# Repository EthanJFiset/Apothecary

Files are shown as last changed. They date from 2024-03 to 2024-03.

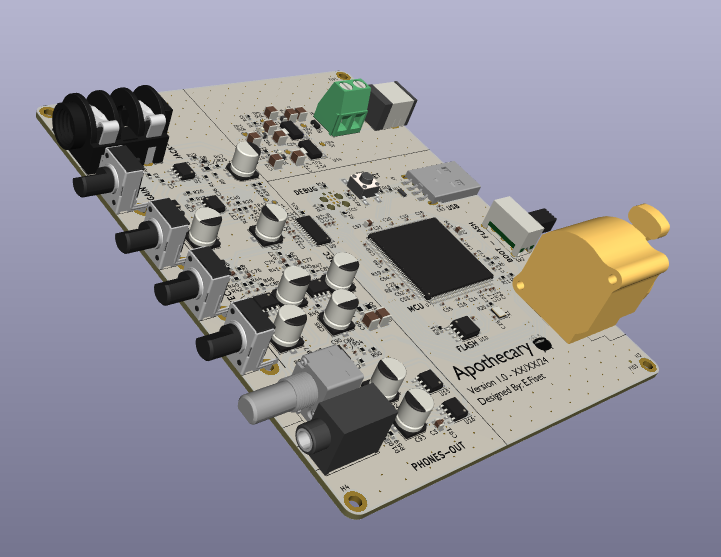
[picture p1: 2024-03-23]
Apothecary - DSP Development Board.png

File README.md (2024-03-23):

# Apothecary
Apothocary is an STM32H7-based USB audio interface and DSP board designed for prototyping real-time guitar effects. Features include a robust STM32H7 MCU complete with external SDRAM and QPSI flash memory, 24-bit 144-dB stereo codec, USB 2.0 connectivity and expansion ports for an external stomp box.

Apothecary - DSP Development Board

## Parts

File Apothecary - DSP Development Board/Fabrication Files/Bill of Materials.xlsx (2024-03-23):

Date: | 2024-03-13 13:44
Project: | Apothecary DSP Board v1.0
Tool: | Eeschema 7.0.9
Component Count: | 183
Ref | Qnty | Description | Footprint | Mfg. Part # | Mfg. | Type | Notes
C1, C2, C8, C12, C13, C14, C15, C16, C17, C18, C19, C20, C21, C22, C23, C25, C27, C28, C30, C31, C33, C36, C37, C38, C43, C44, C45, C46, C47, C48, C49, C50, C52, C54, C56, C58, C59, C60, C61, C88, C89, C90, C91, C94 | 44 | 100n CAP CER X7R 25V 10% | 0402 | C0402C104K3R | Kemet | SMD
C3, C4 | 2 | 10u CAP CER X5R 25V 10% | 0805 | C0805C106K3P7210 | Kemet | SMD
C5, C9, C10, C11, C24, C71, C72, C73, C95, C96 | 10 | 22u CAP CER X7R 24V 5% | 1210 | C1210C226K3PAC | Kemet | SMD
C26, C29, C32, C34, C53, C62, C63 | 7 | 1u CAP CER X7R 24V 5% | 0805 | C0805C105J3RECTU | Kemet | SMD
C35 | 1 | 47u CAP AL. ELC 25V 20% | SMD 6.3x6.3x8mm | EEV476M025A9GAA | Kemet | SMD
C39, C40, C78, C79, C80, C81 | 6 | 470p CAP CER C0G 25V 5% | 0402 | C0402C471J3G | Kemet | SMD
C42, C51, C55, C57 | 4 | 2u2 CAP CER X5R 24V 5% | 0805 | C0805C225K3P | Kemet | SMD
C74, C75, C76, C77, C41 | 4 | 2700p CAP CER C0G 25V 5% | 0603 | C0603C272J3G | Kemet | SMD
C6, C7, C82, C83, C84, C85, C92, C93 | 6 | 100u CAP AL. ELC 25V 20% | SMD 6.3x6.3x8mm | EEV227M025S9MAA | Kemet | SMD
C86, C87 | 2 | 100p CAP CER C0G 25V 5% | 0402 | C0402C101J3G | Kemet | SMD
D1, D2 | 2 | Schottky Diode Vf = 0.51 1A SBR 40Vrm | SOD-123 | 1N5819HW | Diodes Inc. | SMD
D3, D4 | 2 | Red LED, Vf = 2V @ 20mA | 0603 | 150060RS75000 | Wurth Elektronik | SMD
D7, D8, D9, D10 | 4 | ESD Diode 30 Vw, 0.15pF, 15kV Vc | 0603 | 0603ESDA-5N | Bussman-Eaton | SMD
FB1, FB2, FB3 | 3 | Ferrite Bead 1000MHz 10Ohm 3000mA AEC-Q200 | 0805 | 742792011 (https://www.mouser.be/ProductDetail/Wurth-Elektronik/742792011?qs=2kOmHSv6VfQxrmdQ6EIv1w%3D%3D) | Wurth Elektronik | SMD
J1 | 1 | 5-Pin Female XLR Jack | NC5FAH | NC5FAH | Neutrik | THT
J2 | 1 | 6.3mm Mono Female Jack | NMJ4HCD2 | NMJ4HCD2 | Neutrik | THT
J3 | 1 | Female USB 2.0 Jack, Middle mount | SMD | 0480372200 | Molex | SMD
J4 | 1 | Female DC Barrel Jack, 8.0A | THT | PJ-063AH | CUI Devices | THT
J5 | 1 | 3-Pin Stereo 3.5mm Phones Jack, Ground Connection | THT | SJ1-3535NG | CUI Devices | THT
J6 | 1 | 01x02 THT Screw Terminal Block | Terminal Block 1x02 P5.00mm | 1729128 | Pheonix Contact | THT
Q1 | 1 | P-Channel Enhancement Mode MOSFET | SOT-23 | NTR4502P | Onsemi | SMD
R1, R2, R3, R10, R26, R27, R29 | 7 | 680R RES OHM 1/10W .5% | 0603 | ERA-3AEB681V | Panasonic | SMD
R4, R6, R19, R20 | 6 | 33R RES OHM 1/10W .5% | 0603 | ERA-3AEB330V | Panasonic | SMD
R5, R8, R23, R31 | 4 | 20k RES OHM 1/10W .5% | 0603 | ERA-3AEB203V | Panasonic | SMD
R7, R42, R43, R44, R45, R50, R51 | 7 | 910R RES OHM 1/10W .5% | 0603 | ERA-3AEB911V | Panasonic | SMD
R9, R11, R36, R37, R38, R39, R40, R41, R46, R47, R54, R55, R58, R59 | 14 | 6K2 RES 1/10W .5% | 0603 | ERA-3AEB622V | Panasonic | SMD
R12, R18, R21, R48, R49, R52, R53 | 7 | 20K RES 1/10W .5% | 0603 | ERA-3AEB203V | Panasonic | SMD
R13, R14, R15, R16, R22, R28, R30, R32, R33 | 7 | 91R RES 1/10W .5% | 0603 | ERA-3AEB910V | Panasonic | SMD
R17, R60, R61 | 3 | 1M RES 1/8W .5% | 0805 | ERA-6AEB105V | Panasonic | SMD
R24 | 1 | 13K RES 1/10W .5% | 0603 | ERA-3AEB133V | Panasonic | SMD
R25 | 1 | 12K RES 1/10W .5% | 0603 | ERA-3AEB123V | Panasonic | SMD
RV1 | 1 | 1K OHM POT 1/10W 20% AUDIO TAPER | THT | PTV09A-2015F-A102 | Bourns | THT
RV2, RV3, RV4 | 3 | 10K OHM POT 1/10W 20% LINEAR TAPER | THT | PTV09A-2015F-B103 | Bourns | THT
RV5 | 1 | 10K OHM POT .025W 20% AUDIO TAPER, DUAL-GANGED | THT | PTD902-2015F-A103 | Bourns | THT
SW1 | 1 | SPST Push-button | SMD | TS04-66-50-BK-100-SMT | CUI Devices | SMD
SW2 | 1 | SPDT Horizontal Mounted Switch | THT | EG1224 | E-Switch | THT
U1, U2, U4, U5, U6 | 5 | Dual Rail-Rail Operational Amplifier | SOIC-8-1EP 3.9x4.9mm P1.27mm EP2.41x3.81mm | TLV9362IDR | Texas Instruments | SMD
U3 | 1 | 1A Low Dropout regulator, positive, 5.0V fixed output, SOT-223 | SOT-223 | AMS1117-5.0 | AMS | SMD
U7 | 1 | ARM Cortex-M7 MCU, 2048KB flash, 864KB RAM, 400MHz, 1.7-3.6V, 140 GPIO, LQFP-176 | LQFP-176 24x24mm P0.5mm | STM32H743IIT6 | ST Microelectronics | SMD
U8 | 1 | 128 Mb SDRAM, 3.3V, Up To 200MHz TSOP-II | TSOP-II-54 22.2x10.16mm P0.8mm | IS42S16800F-xTL | ISSI | SMD
U9 | 1 | 24-Bit, 192 kHz Stereo Audio CODEC, TSSOP-28 | TSSOP-28 4.4x9.7mm P0.65mm | CS4272-CZZR | Cirrus Logic | SMD
U10 | 1 | 128Mb Serial Flash Memory, Standard/Dual/Quad SPI, SOIC-8 | SOIC-8 5.23x5.23mm P1.27mm | W25Q128JVS | Winbond | SMD
U11 | 1 | USB2.0 ESD Array and Common-Mode Choke | SMD | ECMF02-4CMX8 | ST Microelectronics | SMD
U14 | 1 | 1A Low Dropout regulator, positive, 3.3V fixed output, SOT-223 | SOT-223-3 | AMS1117-3.3 | AMS | SMD
U15, U16 | 2 | High-Voltage High-Current Operational Amplifier, bandwidth 3MHz, slew-rate 15V/us, SOIC-8 | SOIC-8 3.9x4.9mm P1.27mm | OPA551U | Texas Instruments | SMD
X1 | 1 | Low Power Consumption Clock Oscillator - 26MHz | 3225-4Pin 3.2x2.5mm | OT2EL4C4JI-111OLP-26M | LCSC | SMD

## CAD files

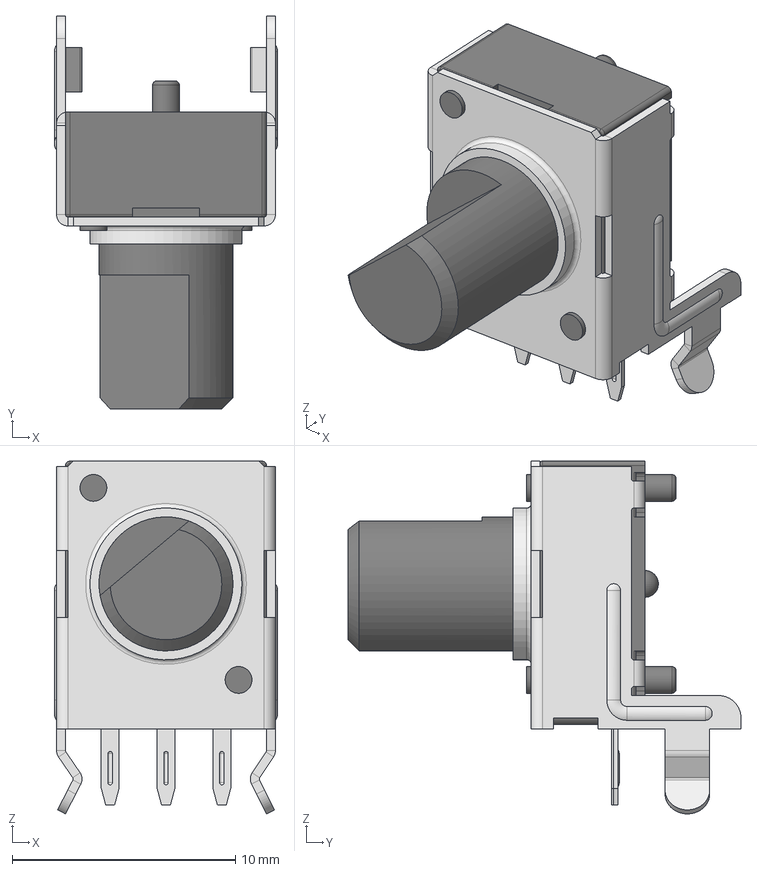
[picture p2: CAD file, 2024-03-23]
Apothecary - DSP Development Board/KiCAD Supplementary Files/3D Models/R-0901N-L-15F_H-6.5-black.step
10.0 x 17.6 x 15.8 mm

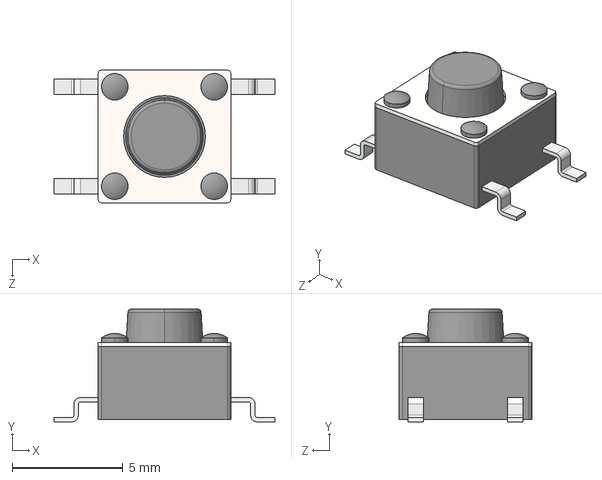
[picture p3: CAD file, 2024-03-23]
Apothecary - DSP Development Board/KiCAD Supplementary Files/3D Models/CUI_DEVICES_TS04-66-50-BK-260-SMT.step
10.0 x 5.10 x 6.00 mm

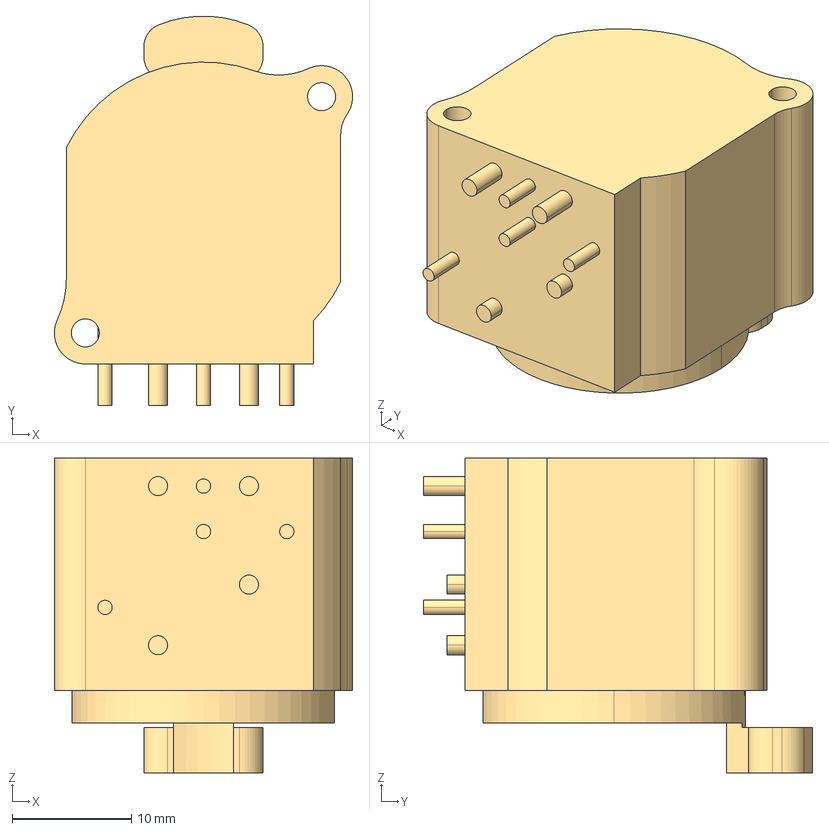
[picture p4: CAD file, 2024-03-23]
Apothecary - DSP Development Board/KiCAD Supplementary Files/3D Models/3-D NC5FAH.stp
25.0 x 32.6 x 26.4 mm

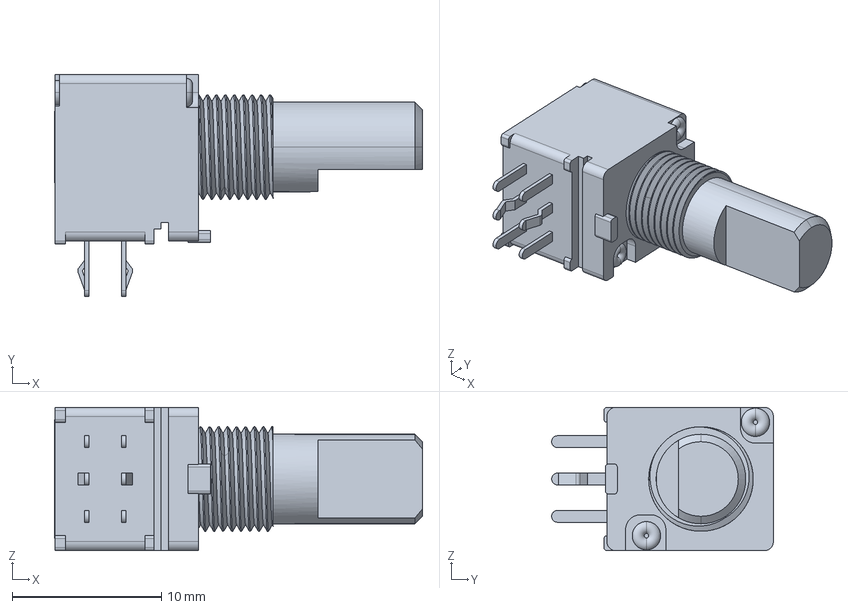
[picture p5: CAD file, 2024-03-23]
Apothecary - DSP Development Board/KiCAD Supplementary Files/3D Models/ptd902-xx15f-xxxx.stp
24.7 x 14.9 x 9.60 mm

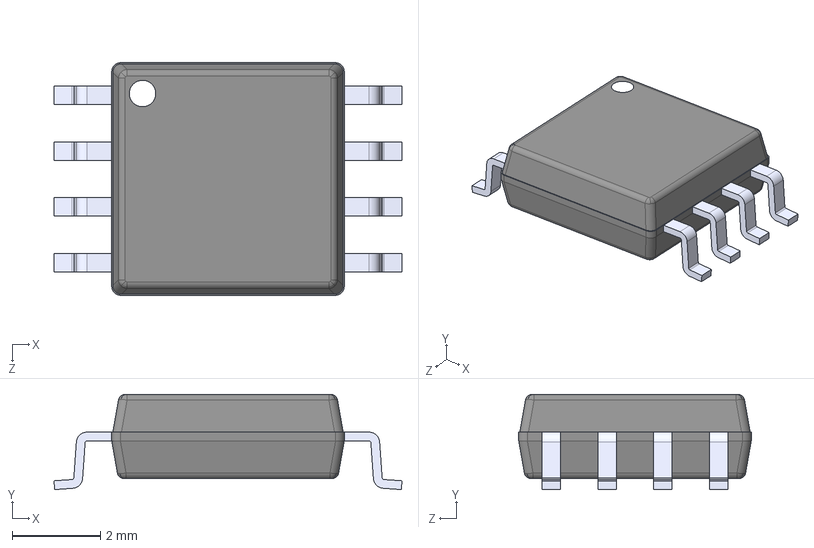
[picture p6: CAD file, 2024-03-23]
Apothecary - DSP Development Board/KiCAD Supplementary Files/3D Models/W25Q128JVSIM.STEP
7.90 x 2.16 x 5.28 mm

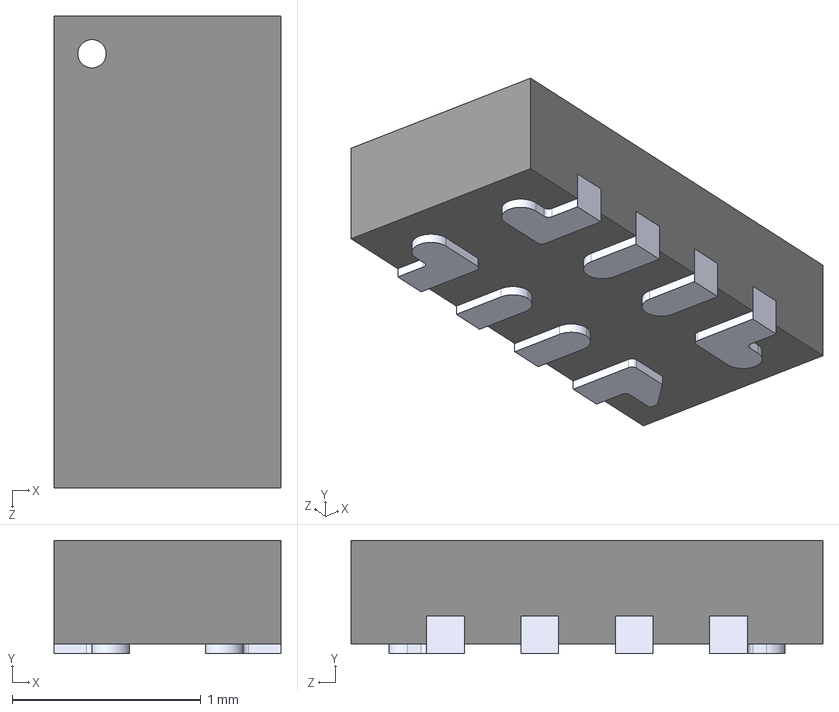
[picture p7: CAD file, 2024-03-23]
Apothecary - DSP Development Board/KiCAD Supplementary Files/3D Models/ECMF02-4CMX8--3DModel-STEP-510211.STEP
1.20 x 0.6 x 2.50 mm

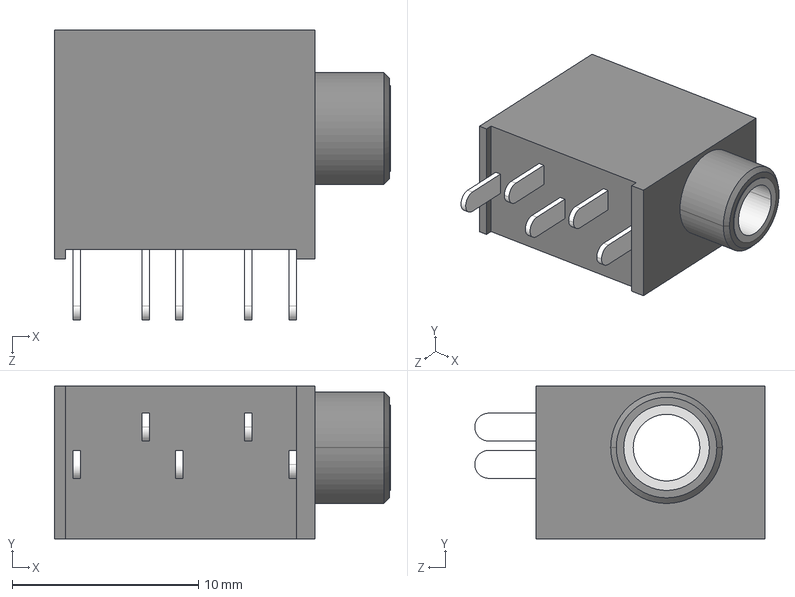
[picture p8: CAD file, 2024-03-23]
Apothecary - DSP Development Board/KiCAD Supplementary Files/3D Models/CUI_DEVICES_SJ1-3535NG.step
18.1 x 8.20 x 15.6 mm

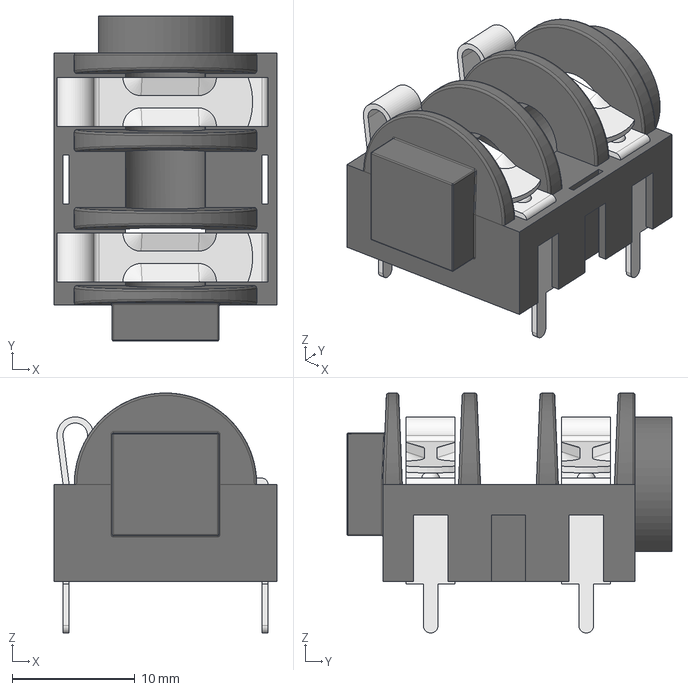
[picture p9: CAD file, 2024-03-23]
Apothecary - DSP Development Board/KiCAD Supplementary Files/3D Models/NMJ4HCD2.step
18.2 x 26.5 x 19.6 mm

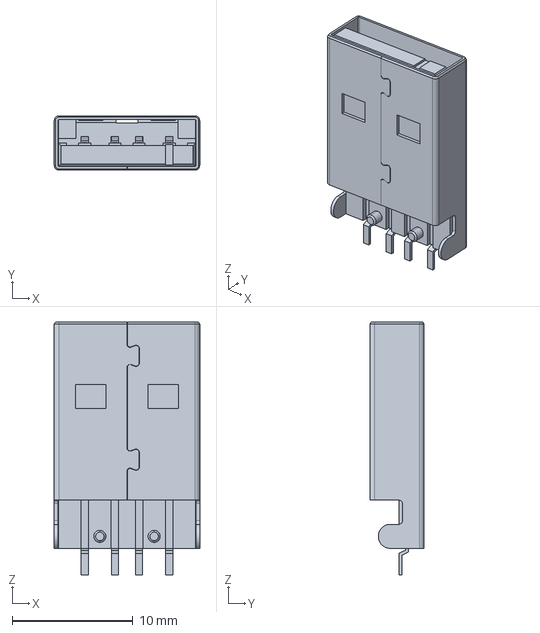
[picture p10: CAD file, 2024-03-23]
Apothecary - DSP Development Board/KiCAD Supplementary Files/3D Models/0480372200.step
12.1 x 4.50 x 21.0 mm

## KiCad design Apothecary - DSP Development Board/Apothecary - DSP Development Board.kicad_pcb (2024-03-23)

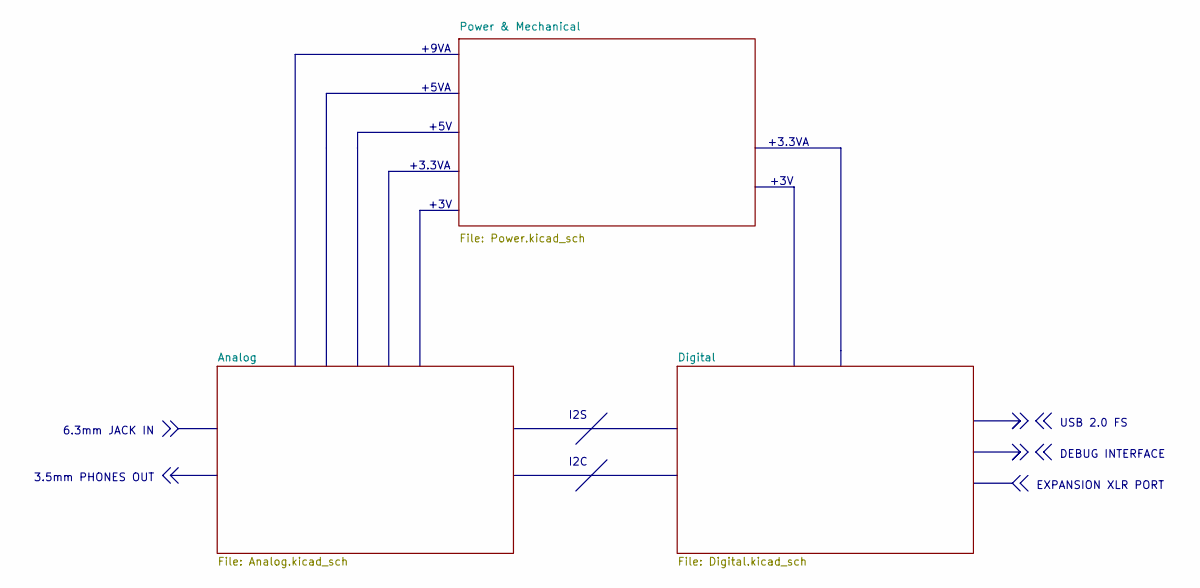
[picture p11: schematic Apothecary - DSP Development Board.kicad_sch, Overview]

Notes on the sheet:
+9VA
+3V
EXPANSION XLR PORT
6.3mm JACK IN
DEBUG INTERFACE
USB 2.0 FS
+5V
I2C
+3.3VA
3.5mm PHONES OUT
+5VA
I2S

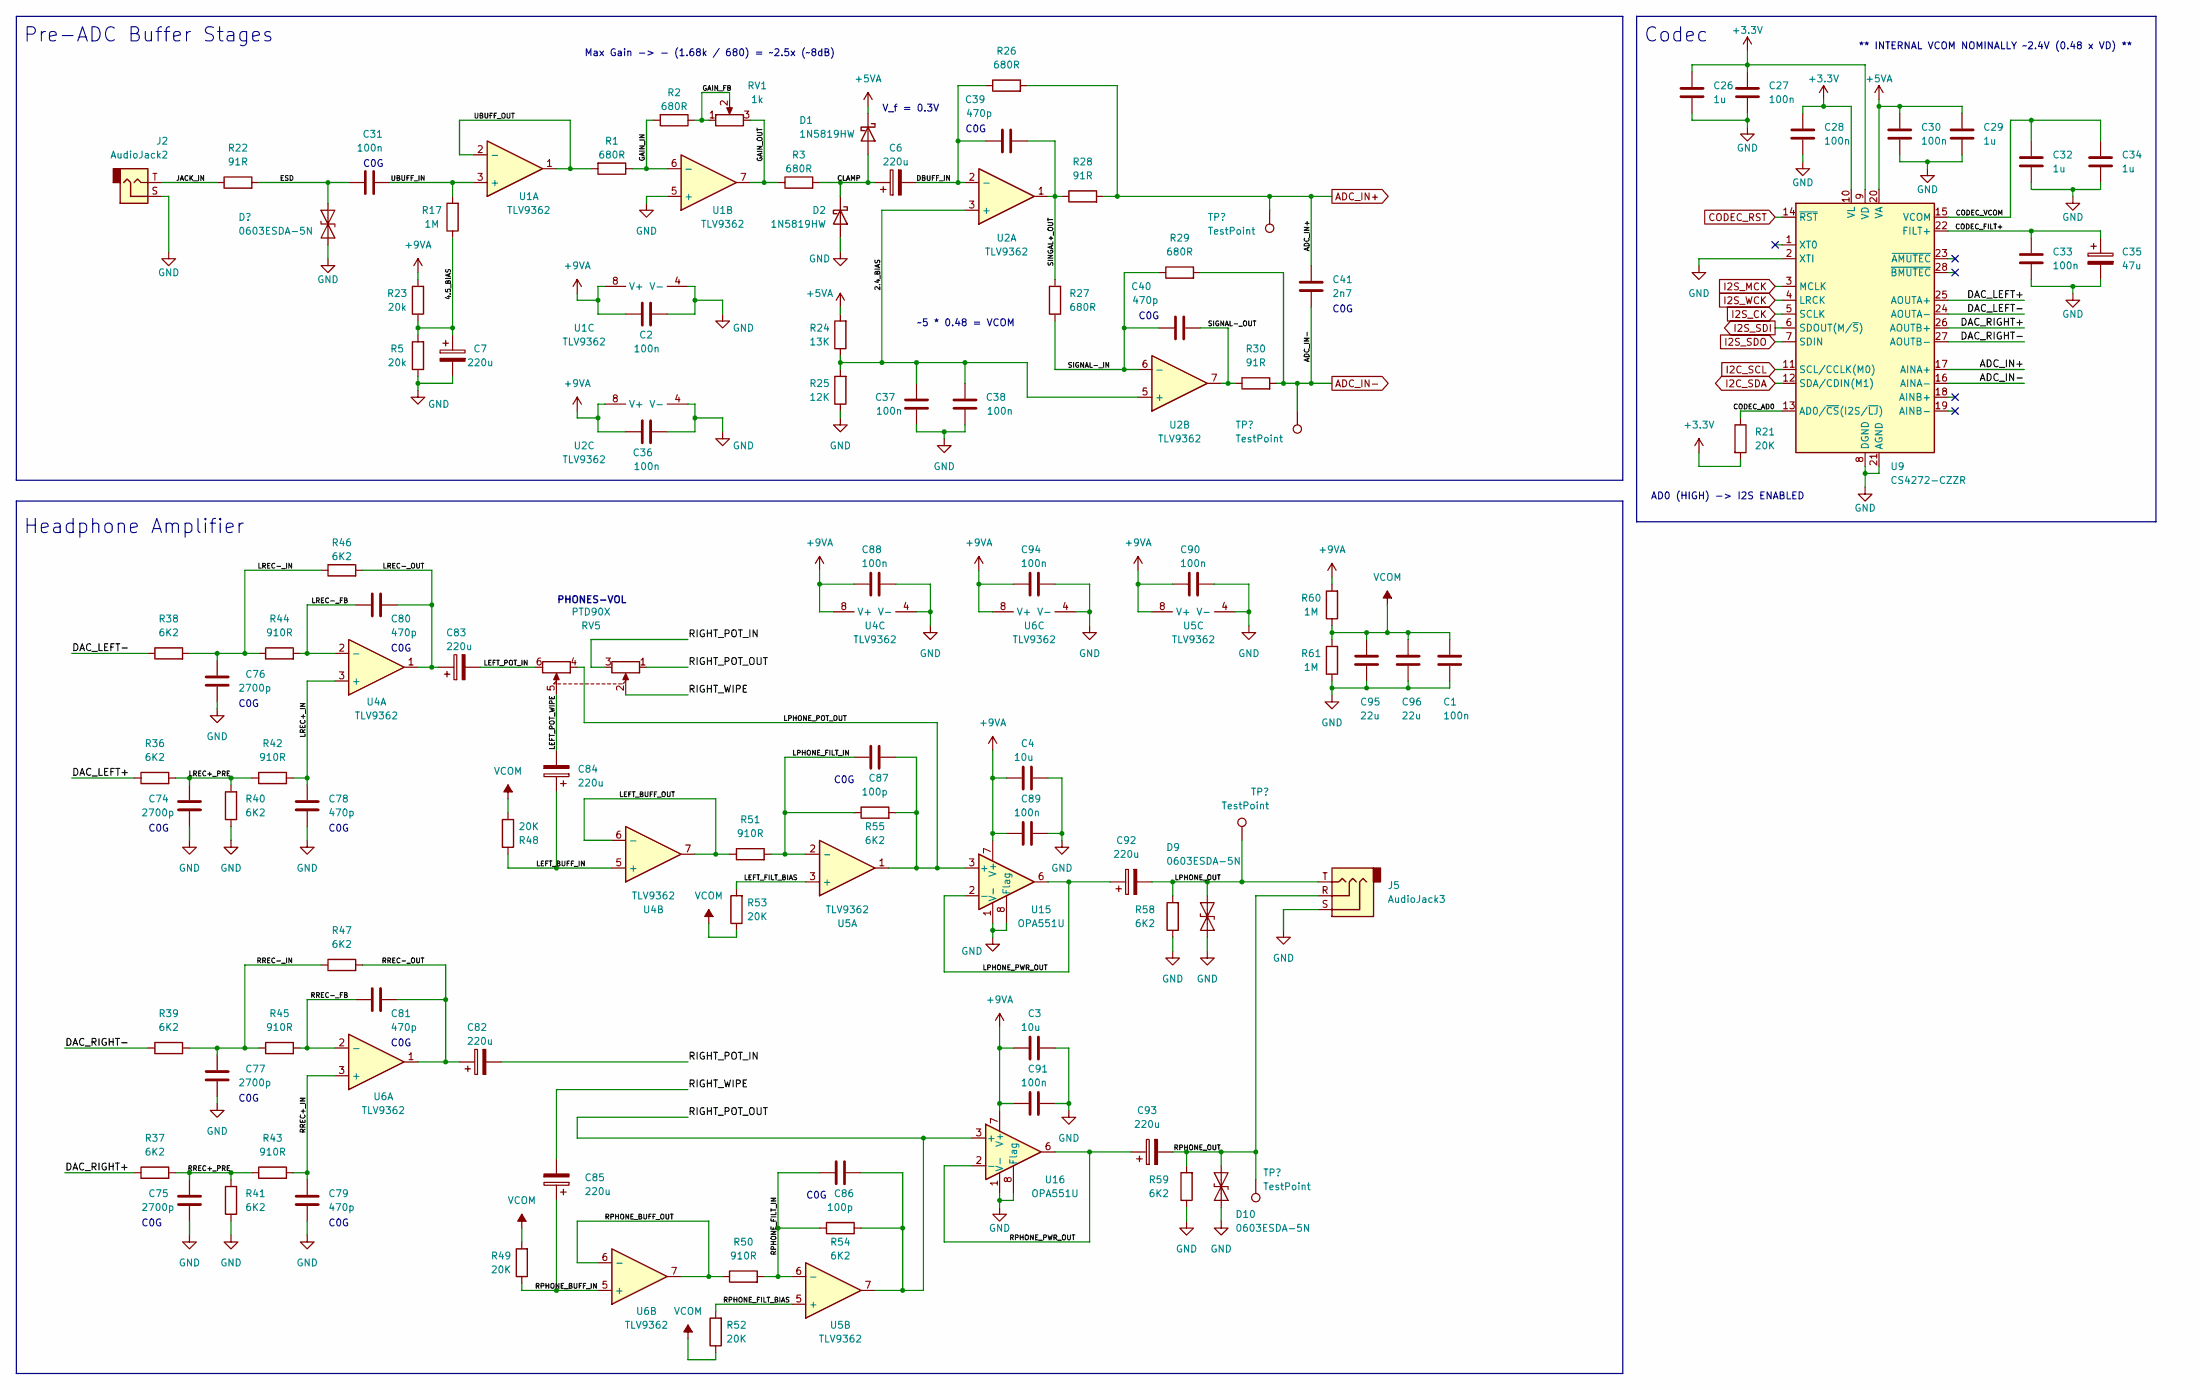
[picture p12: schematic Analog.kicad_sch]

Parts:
C1, C2, C27, C28, C30, C31, C33, C36, C37, C38, C88, C89, C90, C91, C94: 100n; C_0402_1005Metric
C3, C4: 10u; C_0805_2012Metric
C6, C7, C82, C83, C84, C85, C92, C93: 220u; CP_Elec_6.3x7.7
C26, C29, C32, C34: 1u; C_0402_1005Metric
C35: 47u; CP_Elec_6.3x7.7
C39, C40, C78, C79, C80, C81: 470p; C_0402_1005Metric
C41: 2n7; C_0603_1608Metric
C74, C75, C76, C77: 2700p; C_0603_1608Metric
C86, C87: 100p; C_0402_1005Metric
C95, C96: 22u; C_1210_3225Metric
D1, D2: 1N5819HW; D_SOD-123
D8, D9, D10: 0603ESDA-5N; D_0603_1608Metric
J2: AudioJack2; Jack_6.35mm_Neutrik_NMJ4HCD2_Horizontal
J5: AudioJack3; Jack_3.5mm_CUI_SJ1-3533NG_Horizontal
R1, R2, R3, R26, R27, R29: 680R; R_0603_1608Metric
R5, R23: 20k; R_0603_1608Metric
R17, R60, R61: 1M; R_0805_2012Metric
R21, R48, R49, R52, R53: 20K; R_0603_1608Metric
R22, R28, R30: 91R; R_0603_1608Metric
R24: 13K; R_0603_1608Metric
R25: 12K; R_0603_1608Metric
R36, R37, R38, R39, R40, R41, R46, R47, R54, R55, R58, R59: 6K2; R_0603_1608Metric
R42, R43, R44, R45, R50, R51: 910R; R_0603_1608Metric
RV1: 1k; Potentiometer_Bourns_PTV09A-2_Single_Horizontal
RV5: PTD90X; PTD-902
TP11, TP12, TP13, TP14: TestPoint; TestPoint_Pad_D1.0mm
U1, U2, U4, U5, U6: TLV9362; SOIC-8-1EP_3.9x4.9mm_P1.27mm_EP2.41x3.81mm
U9: CS4272-CZZR; TSSOP-28_4.4x9.7mm_P0.65mm
U15, U16: OPA551U; SOIC-8_3.9x4.9mm_P1.27mm

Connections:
+3.3V: C26.1, C27.1, C28.1, R21.2, U9.9 (VD), U9.10 (VL); also elsewhere on the board
+5VA: C29.1, C30.1, D1.1 (K), R24.2, U9.20 (VA); also elsewhere on the board
+9VA: C2.1, C3.2, C4.2, C36.1, C88.2, C89.2, C90.2, C91.2, C94.2, R23.2, R60.2, U1.8 (V+), U2.8 (V+), U4.8 (V+), U5.8 (V+), U6.8 (V+), U15.7 (V+), U16.7 (V+); also elsewhere on the board
/Analog/2.4_BIAS: C37.2, C38.2, R24.1, R25.2, U2.3 (+), U2.5 (+)
/Analog/4.5_BIAS: C7.1, R5.2, R17.1, R23.1
/Analog/CLAMP: C6.1, D1.2 (A), D2.1 (K), R3.2
/Analog/CODEC_AD0: R21.1, U9.13 (AD0/~CS(I2S/~LJ))
/Analog/CODEC_FILT+: C33.1, C35.1, U9.22 (FILT+)
/Analog/CODEC_VCOM: C32.1, C34.1, U9.15 (VCOM)
/Analog/DAC_LEFT+: R36.1, U9.25 (AOUTA+)
/Analog/DAC_LEFT-: R38.1, U9.24 (AOUTA-)
/Analog/DAC_RIGHT+: R37.1, U9.26 (AOUTB+)
/Analog/DAC_RIGHT-: R39.1, U9.27 (AOUTB-)
/Analog/DBUFF_IN: C6.2, C39.1, R26.1, U2.2 (-)
/Analog/ESD: C31.1, D8.2 (A2), R22.2
/Analog/GAIN_FB: R2.1, RV1.1, RV1.2
/Analog/GAIN_IN: R1.1, R2.2, U1.6 (-)
/Analog/GAIN_OUT: R3.1, RV1.3, U1.7
/Analog/JACK_IN: J2.T, R22.1
/Analog/LEFT_BUFF_IN: C84.1, R48.2, U4.5 (+)
/Analog/LEFT_BUFF_OUT: R51.1, U4.6 (-), U4.7
/Analog/LEFT_FILT_BIAS: R53.2, U5.3 (+)
/Analog/LEFT_POT_IN: C83.2, RV5.6
/Analog/LEFT_POT_WIPE: C84.2, RV5.5
/Analog/LPHONE_FILT_IN: C87.2, R51.2, R55.1, U5.2 (-)
/Analog/LPHONE_OUT: C92.2, D9.2 (A2), J5.T, R58.2, TP13.1
/Analog/LPHONE_POT_OUT: C87.1, R55.2, RV5.4, U5.1, U15.3 (+)
/Analog/LPHONE_PWR_OUT: C92.1, U15.2 (-), U15.6
/Analog/LREC+_IN: C78.1, R42.2, U4.3 (+)
/Analog/LREC+_PRE: C74.1, R36.2, R40.2, R42.1
/Analog/LREC-_FB: C80.2, R44.2, U4.2 (-)
/Analog/LREC-_IN: C76.1, R38.2, R44.1, R46.1
/Analog/LREC-_OUT: C80.1, C83.1, R46.2, U4.1
/Analog/RIGHT_POT_IN: C82.2, RV5.3
/Analog/RIGHT_POT_OUT: C86.1, R54.2, RV5.1, U5.7, U16.3 (+)
/Analog/RIGHT_WIPE: C85.2, RV5.2
/Analog/RPHONE_BUFF_IN: C85.1, R49.1, U6.5 (+)
/Analog/RPHONE_BUFF_OUT: R50.1, U6.6 (-), U6.7
/Analog/RPHONE_FILT_BIAS: R52.2, U5.5 (+)
/Analog/RPHONE_FILT_IN: C86.2, R50.2, R54.1, U5.6 (-)
/Analog/RPHONE_OUT: C93.2, D10.2 (A2), J5.R, R59.2, TP14.1
/Analog/RPHONE_PWR_OUT: C93.1, U16.2 (-), U16.6
/Analog/RREC+_IN: C79.1, R43.2, U6.3 (+)
/Analog/RREC+_PRE: C75.1, R37.2, R41.2, R43.1
/Analog/RREC-_FB: C81.2, R45.2, U6.2 (-)
/Analog/RREC-_IN: C77.1, R39.2, R45.1, R47.1
/Analog/RREC-_OUT: C81.1, C82.1, R47.2, U6.1
/Analog/SIGNAL-_IN: C40.1, R27.1, R29.1, U2.6 (-)
/Analog/SIGNAL-_OUT: C40.2, R30.1, U2.7
/Analog/SINGAL+_OUT: C39.2, R27.2, R28.1, U2.1
/Analog/UBUFF_IN: C31.2, R17.2, U1.3 (+)
/Analog/UBUFF_OUT: R1.2, U1.1, U1.2 (-)
ADC_IN+: C41.1, R26.2, R28.2, TP12.1, U9.17 (AINA+)
ADC_IN-: C41.2, R29.2, R30.2, TP11.1, U9.16 (AINA-)
CODEC_RST: U9.14 (~RST); also elsewhere on the board
GND: C1.2, C2.2, C3.1, C4.1, C7.2, C26.2, C27.2, C28.2, C29.2, C30.2, C32.2, C33.2, C34.2, C35.2, C36.2, C37.1, C38.1, C74.2, C75.2, C76.2, C77.2, C78.2, C79.2, C88.1, C89.1, C90.1, C91.1, C94.1, C95.2, C96.2, D2.2 (A), D8.1 (A1), D9.1 (A1), D10.1 (A1), J2.S, J5.S, R5.1, R25.1, R40.1, R41.1, R58.1, R59.1, R61.1, U1.4 (V-), U1.5 (+), U2.4 (V-), U4.4 (V-), U5.4 (V-), U6.4 (V-), U9.2 (XTI), U9.8 (DGND), U9.21 (AGND), U15.1 (V-), U15.4 (V-), U15.5 (V-), U15.8 (Flag), U16.1 (V-), U16.4 (V-), U16.5 (V-), U16.8 (Flag); also elsewhere on the board
I2C_SCL: U9.11 (SCL/CCLK(M0)); also elsewhere on the board
I2C_SDA: U9.12 (SDA/CDIN(M1)); also elsewhere on the board
I2S_CK: U9.5 (SCLK); also elsewhere on the board
I2S_MCK: U9.3 (MCLK); also elsewhere on the board
I2S_SDI: U9.6 (SDOUT(M/~S)); also elsewhere on the board
I2S_SDO: U9.7 (SDIN); also elsewhere on the board
I2S_WCK: U9.4 (LRCK); also elsewhere on the board
VCOM: C1.1, C95.1, C96.1, R48.1, R49.2, R52.1, R53.1, R60.1, R61.2

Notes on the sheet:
C0G
Pre-ADC Buffer Stages
** INTERNAL VCOM NOMINALLY ~2.4V (0.48 x VD) **
Headphone Amplifier
V_f = 0.3V
PHONES-VOL
Codec
~5 * 0.48 = VCOM
AD0 (HIGH) -> I2S ENABLED
Max Gain -> - (1.68k / 680) = ~2.5x (~8dB)

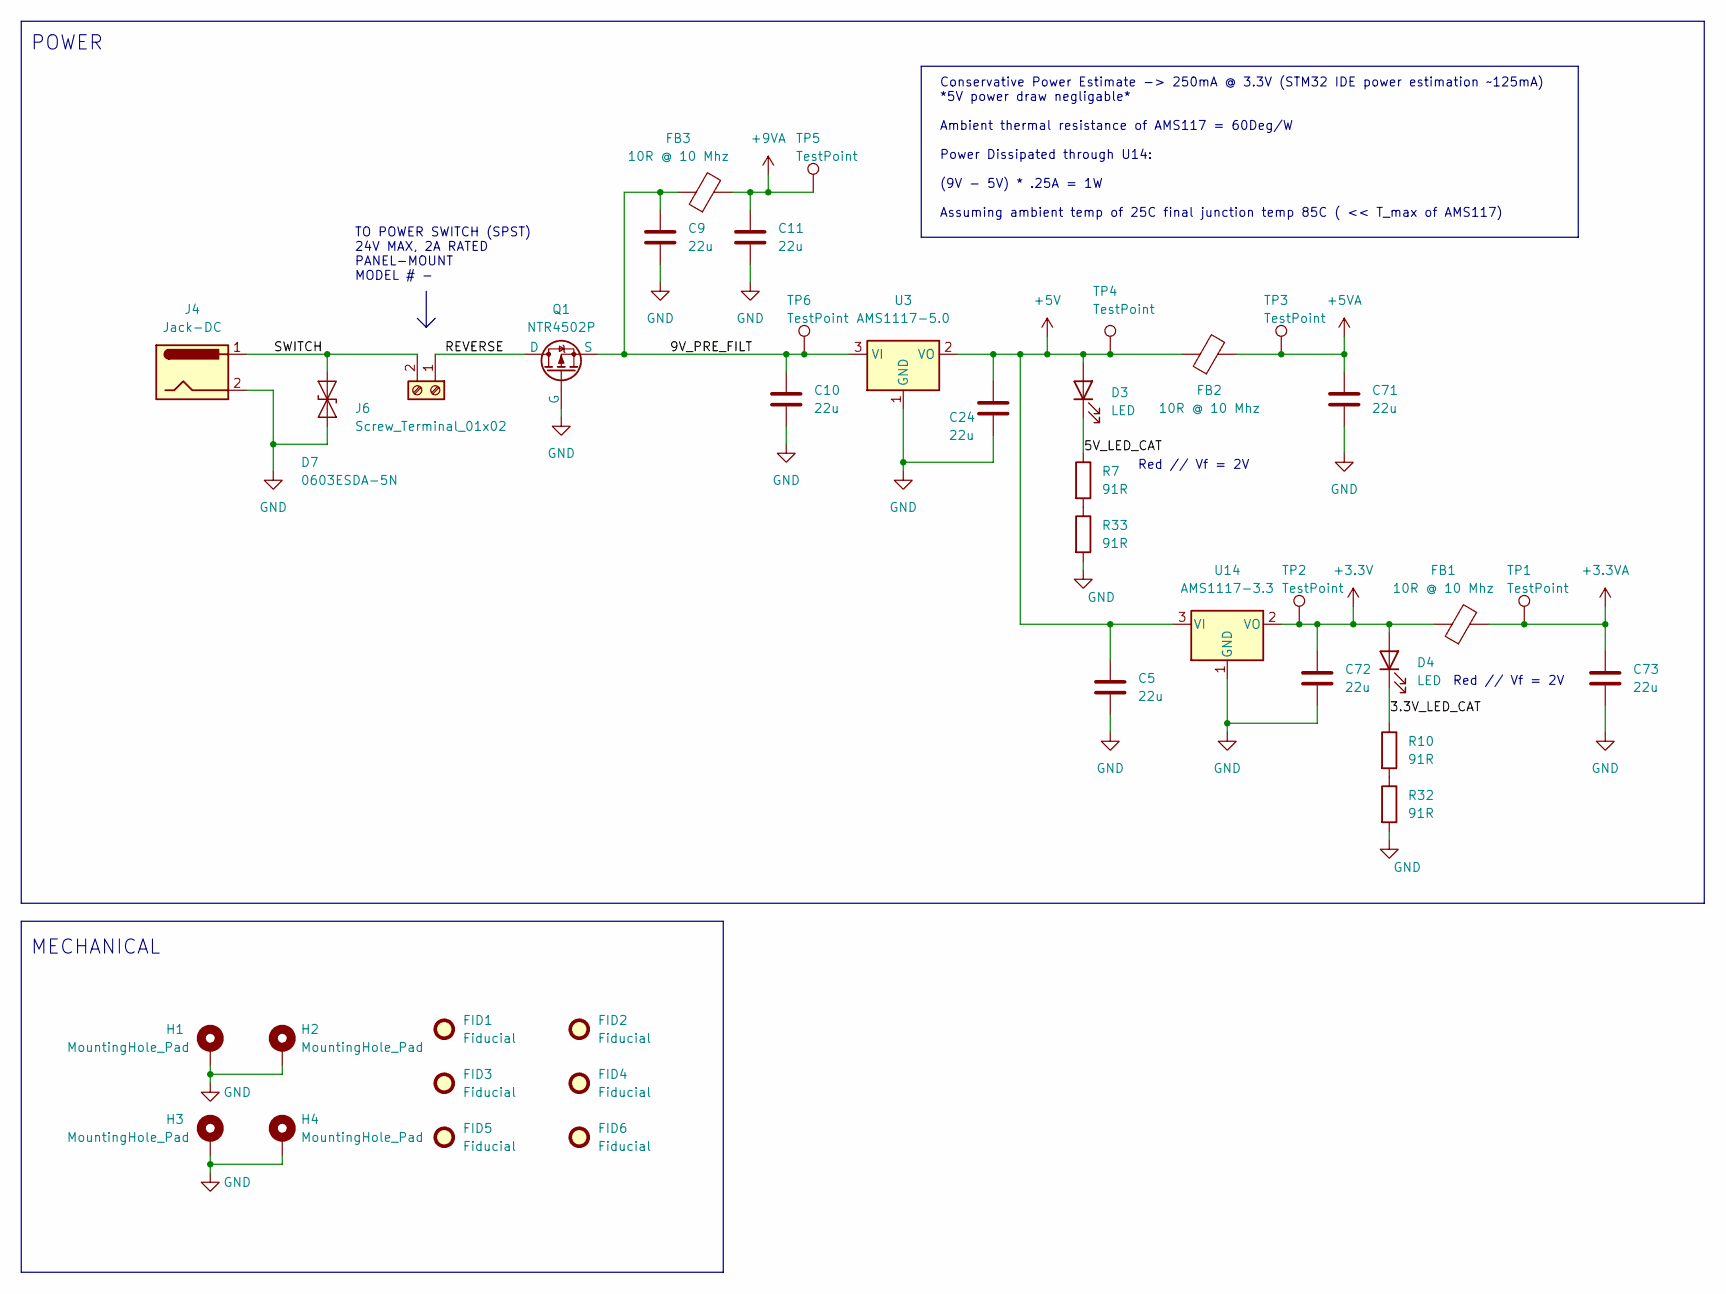
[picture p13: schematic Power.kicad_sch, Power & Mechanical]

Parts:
C5, C9, C10, C11, C24, C71, C72, C73: 22u; C_1210_3225Metric
D3, D4: LED; LED_0603_1608Metric
D7: 0603ESDA-5N; D_0603_1608Metric
FB1, FB2, FB3: 10R @ 10 Mhz; L_0805_2012Metric
FID1, FID2, FID3, FID4, FID5, FID6: Fiducial; Fiducial_0.5mm_Mask1mm
H1, H2, H3, H4: MountingHole_Pad; MountingHole_2.7mm_M2.5_DIN965_Pad
J4: Jack-DC; BarrelJack_CUI_PJ-063AH_Horizontal
J6: Screw_Terminal_01x02; TerminalBlock_Phoenix_MKDS-1,5-2_1x02_P5.00mm_Horizontal
Q1: NTR4502P; SOT-23
R7, R10, R32, R33: 91R; R_0603_1608Metric
TP1, TP2, TP3, TP4, TP5, TP6: TestPoint; TestPoint_Pad_D1.5mm
U3: AMS1117-5.0; SOT-223-3_TabPin2
U14: AMS1117-3.3; SOT-223-3_TabPin2

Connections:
+3.3V: C72.2, D4.2 (A), FB1.1, TP2.1, U14.2 (VO); also elsewhere on the board
+3.3VA: C73.2, FB1.2, TP1.1; also elsewhere on the board
+5V: C5.2, C24.2, D3.2 (A), FB2.1, TP4.1, U3.2 (VO), U14.3 (VI)
+5VA: C71.2, FB2.2, TP3.1; also elsewhere on the board
+9VA: C11.2, FB3.2, TP5.1; also elsewhere on the board
/Power & Mechanical/3.3V_LED_CAT: D4.1 (K), R10.1
/Power & Mechanical/5V_LED_CAT: D3.1 (K), R7.1
/Power & Mechanical/9V_PRE_FILT: C9.2, C10.2, FB3.1, Q1.3 (S), TP6.1, U3.3 (VI)
/Power & Mechanical/REVERSE: J6.1, Q1.1 (D)
/Power & Mechanical/SWITCH: D7.2 (A2), J4.1, J6.2
GND: C5.1, C9.1, C10.1, C11.1, C24.1, C71.1, C72.1, C73.1, D7.1 (A1), H1.1, H2.1, H3.1, H4.1, J4.2, Q1.2 (G), R32.2, R33.2, U3.1 (GND), U14.1 (GND); also elsewhere on the board
unnamed: R10.2, R32.1
unnamed: R7.2, R33.1

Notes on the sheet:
Conservative Power Estimate -> 250mA @ 3.3V (STM32 IDE power estimation ~125mA) *5V power draw negligable* Ambient thermal resistance of AMS117 = 60Deg/W Power Dissipated through U14: (9V - 5V) * .25A = 1W Assuming ambient temp of 25C final junction temp 85C ( << T_max of AMS117)
TO POWER SWITCH (SPST) 24V MAX, 2A RATED PANEL-MOUNT MODEL # -
MECHANICAL
POWER
Red // Vf = 2V

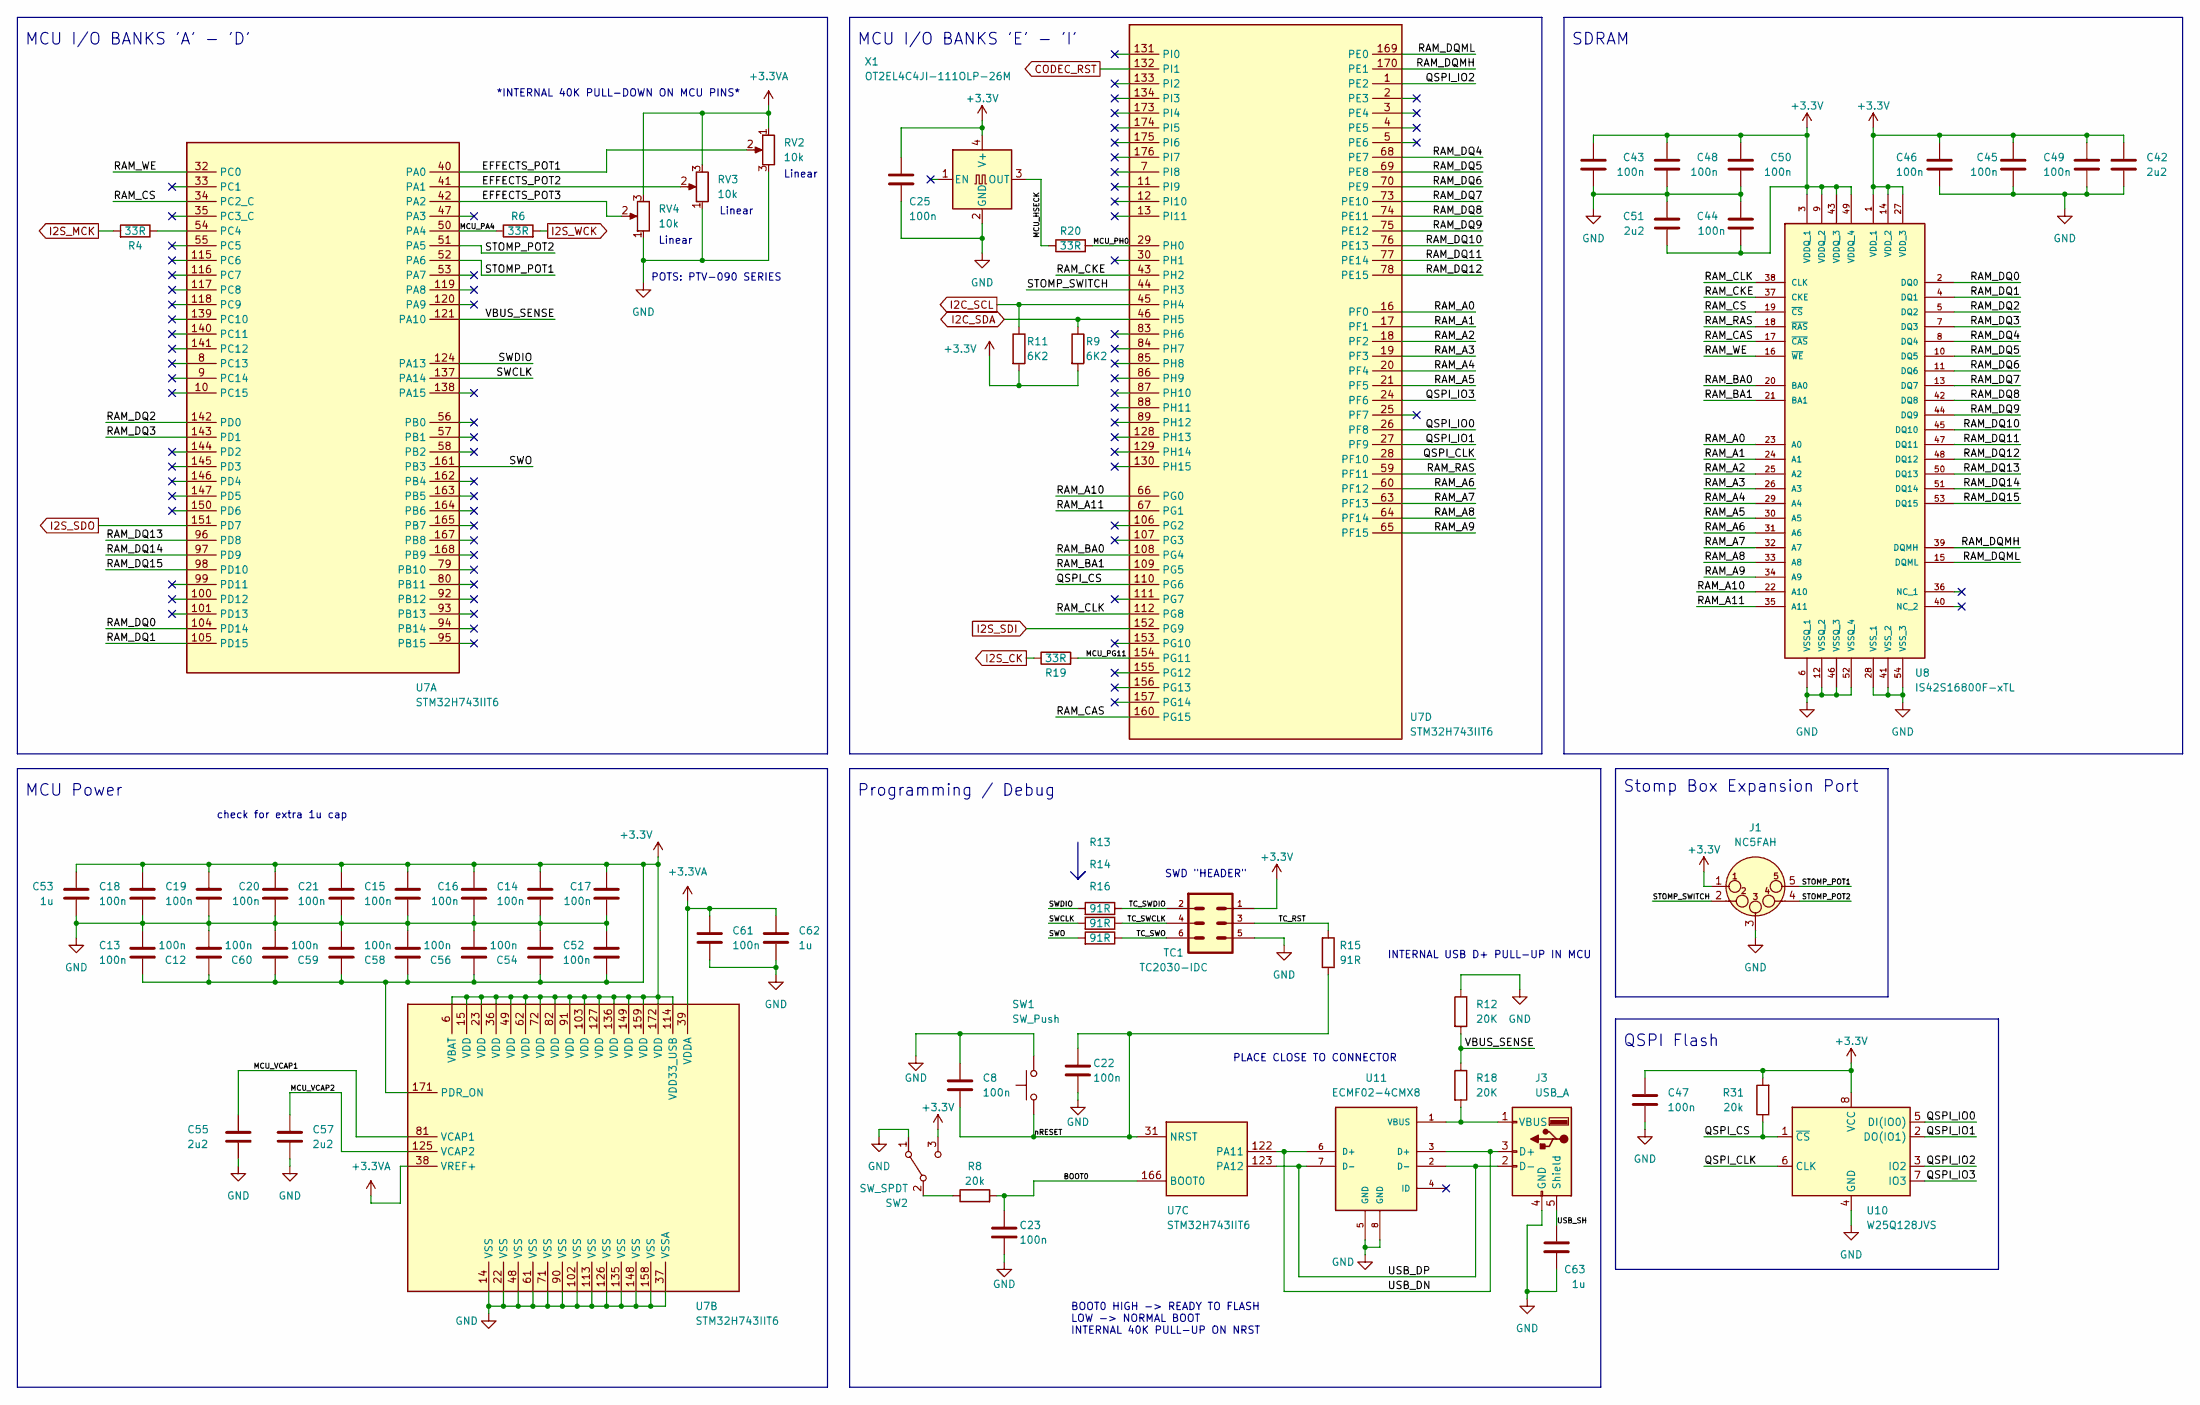
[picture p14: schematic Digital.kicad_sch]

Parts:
C8, C12, C13, C14, C15, C16, C17, C18, C19, C20, C21, C22, C23, C25, C43, C44, C45, C46, C47, C48, C49, C50, C52, C54, C56, C58, C59, C60, C61: 100n; C_0402_1005Metric
C42, C51, C55, C57: 2u2; C_0805_2012Metric
C53, C62, C63: 1u; C_0402_1005Metric
J1: NC5FAH; Jack_XLR_Neutrik_NC5FAH_Horizontal
J3: USB_A; MOLEX_0480372200
R4, R6, R19, R20: 33R; R_0603_1608Metric
R8, R31: 20k; R_0603_1608Metric
R9, R11: 6K2; R_0603_1608Metric
R12, R18: 20K; R_0603_1608Metric
R13, R14, R15, R16: 91R; R_0603_1608Metric
RV2, RV3, RV4: 10k; Potentiometer_Bourns_PTV09A-2_Single_Horizontal
SW1: SW_Push; Pushbutton_CUI_TS04
SW2: SW_SPDT; SW_E-Switch_EG1224_SPDT_Angled
TC1: TC2030-IDC; Tag-Connect_TC2030-IDC-FP_2x03_P1.27mm_Vertical
U7: STM32H743IIT6; LQFP-176_24x24mm_P0.5mm
U8: IS42S16800F-xTL; TSOP-II-54_22.2x10.16mm_P0.8mm; MOUSER_PART_NUMBER 870-IS42S16800F-7TL
U10: W25Q128JVS; SOIC-8_5.23x5.23mm_P1.27mm
U11: ECMF02-4CMX8; FIL_ECMF02-4CMX8; PARTREV 3
X1: OT2EL4C4JI-111OLP-26M; Crystal_SMD_3225-4Pin_3.2x2.5mm

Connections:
+3.3V: C12.1, C13.1, C14.2, C15.2, C16.2, C17.2, C18.2, C19.2, C20.2, C21.2, C25.1, C42.2, C43.2, C44.1, C45.2, C46.2, C47.1, C48.2, C49.2, C50.2, C51.1, C52.1, C53.2, C54.1, C56.1, C58.1, C59.1, C60.1, J1.1, R9.2, R11.2, R31.2, SW2.3 (C), TC1.1, U7.6 (VBAT), U7.15 (VDD), U7.23 (VDD), U7.36 (VDD), U7.49 (VDD), U7.62 (VDD), U7.72 (VDD), U7.82 (VDD), U7.91 (VDD), U7.103 (VDD), U7.114 (VDD33_USB), U7.127 (VDD), U7.136 (VDD), U7.149 (VDD), U7.159 (VDD), U7.171 (PDR_ON), U7.172 (VDD), U8.1 (VDD_1), U8.3 (VDDQ_1), U8.9 (VDDQ_2), U8.14 (VDD_2), U8.27 (VDD_3), U8.43 (VDDQ_3), U8.49 (VDDQ_4), U10.8 (VCC), X1.4 (V+); also elsewhere on the board
+3.3VA: C61.1, C62.1, RV2.1, RV3.3, RV4.3, U7.38 (VREF+), U7.39 (VDDA); also elsewhere on the board
/Digital/BOOT0: C23.1, R8.2, U7.166 (BOOT0)
/Digital/EFFECTS_POT1: RV2.2, U7.40 (PA0)
/Digital/EFFECTS_POT2: RV3.2, U7.41 (PA1)
/Digital/EFFECTS_POT3: RV4.2, U7.42 (PA2)
/Digital/MCU_HSECK: R20.1, X1.3 (OUT)
/Digital/MCU_PA4: R6.1, U7.50 (PA4)
/Digital/MCU_PG11: R19.2, U7.154 (PG11)
/Digital/MCU_PH0: R20.2, U7.29 (PH0)
/Digital/MCU_VCAP1: C55.1, U7.81 (VCAP1)
/Digital/MCU_VCAP2: C57.1, U7.125 (VCAP2)
/Digital/QSPI_CLK: U7.28 (PF10), U10.6 (CLK)
/Digital/QSPI_CS: R31.1, U7.110 (PG6), U10.1 (~CS)
/Digital/QSPI_IO0: U7.26 (PF8), U10.5 (DI(IO0))
/Digital/QSPI_IO1: U7.27 (PF9), U10.2 (DO(IO1))
/Digital/QSPI_IO2: U7.1 (PE2), U10.3 (IO2)
/Digital/QSPI_IO3: U7.24 (PF6), U10.7 (IO3)
/Digital/RAM_A0: U7.16 (PF0), U8.23 (A0)
/Digital/RAM_A1: U7.17 (PF1), U8.24 (A1)
/Digital/RAM_A2: U7.18 (PF2), U8.25 (A2)
/Digital/RAM_A3: U7.19 (PF3), U8.26 (A3)
/Digital/RAM_A4: U7.20 (PF4), U8.29 (A4)
/Digital/RAM_A5: U7.21 (PF5), U8.30 (A5)
/Digital/RAM_A6: U7.60 (PF12), U8.31 (A6)
/Digital/RAM_A7: U7.63 (PF13), U8.32 (A7)
/Digital/RAM_A8: U7.64 (PF14), U8.33 (A8)
/Digital/RAM_A9: U7.65 (PF15), U8.34 (A9)
/Digital/RAM_A10: U7.66 (PG0), U8.22 (A10)
/Digital/RAM_A11: U7.67 (PG1), U8.35 (A11)
/Digital/RAM_BA0: U7.108 (PG4), U8.20 (BA0)
/Digital/RAM_BA1: U7.109 (PG5), U8.21 (BA1)
/Digital/RAM_CAS: U7.160 (PG15), U8.17 (~CAS)
/Digital/RAM_CKE: U7.43 (PH2), U8.37 (CKE)
/Digital/RAM_CLK: U7.112 (PG8), U8.38 (CLK)
/Digital/RAM_CS: U7.34 (PC2_C), U8.19 (~CS)
/Digital/RAM_DQ0: U7.104 (PD14), U8.2 (DQ0)
/Digital/RAM_DQ1: U7.105 (PD15), U8.4 (DQ1)
/Digital/RAM_DQ2: U7.142 (PD0), U8.5 (DQ2)
/Digital/RAM_DQ3: U7.143 (PD1), U8.7 (DQ3)
/Digital/RAM_DQ4: U7.68 (PE7), U8.8 (DQ4)
/Digital/RAM_DQ5: U7.69 (PE8), U8.10 (DQ5)
/Digital/RAM_DQ6: U7.70 (PE9), U8.11 (DQ6)
/Digital/RAM_DQ7: U7.73 (PE10), U8.13 (DQ7)
/Digital/RAM_DQ8: U7.74 (PE11), U8.42 (DQ8)
/Digital/RAM_DQ9: U7.75 (PE12), U8.44 (DQ9)
/Digital/RAM_DQ10: U7.76 (PE13), U8.45 (DQ10)
/Digital/RAM_DQ11: U7.77 (PE14), U8.47 (DQ11)
/Digital/RAM_DQ12: U7.78 (PE15), U8.48 (DQ12)
/Digital/RAM_DQ13: U7.96 (PD8), U8.50 (DQ13)
/Digital/RAM_DQ14: U7.97 (PD9), U8.51 (DQ14)
/Digital/RAM_DQ15: U7.98 (PD10), U8.53 (DQ15)
/Digital/RAM_DQMH: U7.170 (PE1), U8.39 (DQMH)
/Digital/RAM_DQML: U7.169 (PE0), U8.15 (DQML)
/Digital/RAM_RAS: U7.59 (PF11), U8.18 (~RAS)
/Digital/RAM_WE: U7.32 (PC0), U8.16 (~WE)
/Digital/STOMP_POT1: J1.5, U7.52 (PA6)
/Digital/STOMP_POT2: J1.4 (P3), U7.51 (PA5)
/Digital/STOMP_SWITCH: J1.2, U7.44 (PH3)
/Digital/SWCLK: R14.2, U7.137 (PA14)
/Digital/SWDIO: R13.2, U7.124 (PA13)
/Digital/SWO: R16.2, U7.161 (PB3)
/Digital/TC_RST: R15.2, TC1.3
/Digital/TC_SWCLK: R14.1, TC1.4
/Digital/TC_SWDIO: R13.1, TC1.2
/Digital/TC_SWO: R16.1, TC1.6
/Digital/USB_DN: J3.3 (D+), U7.122 (PA11), U11.3 (D+), U11.6 (D+)
/Digital/USB_DP: J3.2 (D-), U7.123 (PA12), U11.2 (D-), U11.7 (D-)
/Digital/USB_SH: C63.1, J3.5 (Shield)
/Digital/VBUS_SENSE: R12.2, R18.1, U7.121 (PA10)
/Digital/nRESET: C8.2, C22.1, R15.1, SW1.1, U7.31 (NRST)
CODEC_RST: U7.132 (PI1); also elsewhere on the board
GND: C8.1, C12.2, C13.2, C14.1, C15.1, C16.1, C17.1, C18.1, C19.1, C20.1, C21.1, C22.2, C23.2, C25.2, C42.1, C43.1, C44.2, C45.1, C46.1, C47.2, C48.1, C49.1, C50.1, C51.2, C52.2, C53.1, C54.2, C55.2, C56.2, C57.2, C58.2, C59.2, C60.2, C61.2, C62.2, C63.2, J1.3, J3.4 (GND), R12.1, RV2.3, RV3.1, RV4.1, SW1.2, SW2.1 (A), TC1.5, U7.14 (VSS), U7.22 (VSS), U7.37 (VSSA), U7.48 (VSS), U7.61 (VSS), U7.71 (VSS), U7.90 (VSS), U7.102 (VSS), U7.113 (VSS), U7.126 (VSS), U7.135 (VSS), U7.148 (VSS), U7.158 (VSS), U8.6 (VSSQ_1), U8.12 (VSSQ_2), U8.28 (VSS_1), U8.41 (VSS_2), U8.46 (VSSQ_3), U8.52 (VSSQ_4), U8.54 (VSS_3), U10.4 (GND), U11.5 (GND), U11.8 (GND), X1.2 (GND); also elsewhere on the board
I2C_SCL: R11.1, U7.45 (PH4); also elsewhere on the board
I2C_SDA: R9.1, U7.46 (PH5); also elsewhere on the board
I2S_CK: R19.1; also elsewhere on the board
I2S_MCK: R4.2; also elsewhere on the board
I2S_SDI: U7.152 (PG9); also elsewhere on the board
I2S_SDO: U7.151 (PD7); also elsewhere on the board
I2S_WCK: R6.2; also elsewhere on the board
unnamed: J3.1 (VBUS), R18.2, U11.1 (VBUS)
unnamed: R8.1, SW2.2 (B)
unnamed: R4.1, U7.54 (PC4)

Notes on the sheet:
*INTERNAL 40K PULL-DOWN ON MCU PINS*
Programming / Debug
Linear
PLACE CLOSE TO CONNECTOR
Linear
BOOT0 HIGH -> READY TO FLASH LOW -> NORMAL BOOT INTERNAL 40K PULL-UP ON NRST
SWD "HEADER"
MCU Power
MCU I/O BANKS 'A' - 'D'
INTERNAL USB D+ PULL-UP IN MCU
SDRAM
MCU I/O BANKS 'E' - 'I'
Stomp Box Expansion Port
QSPI Flash
check for extra 1u cap
POTS: PTV-090 SERIES

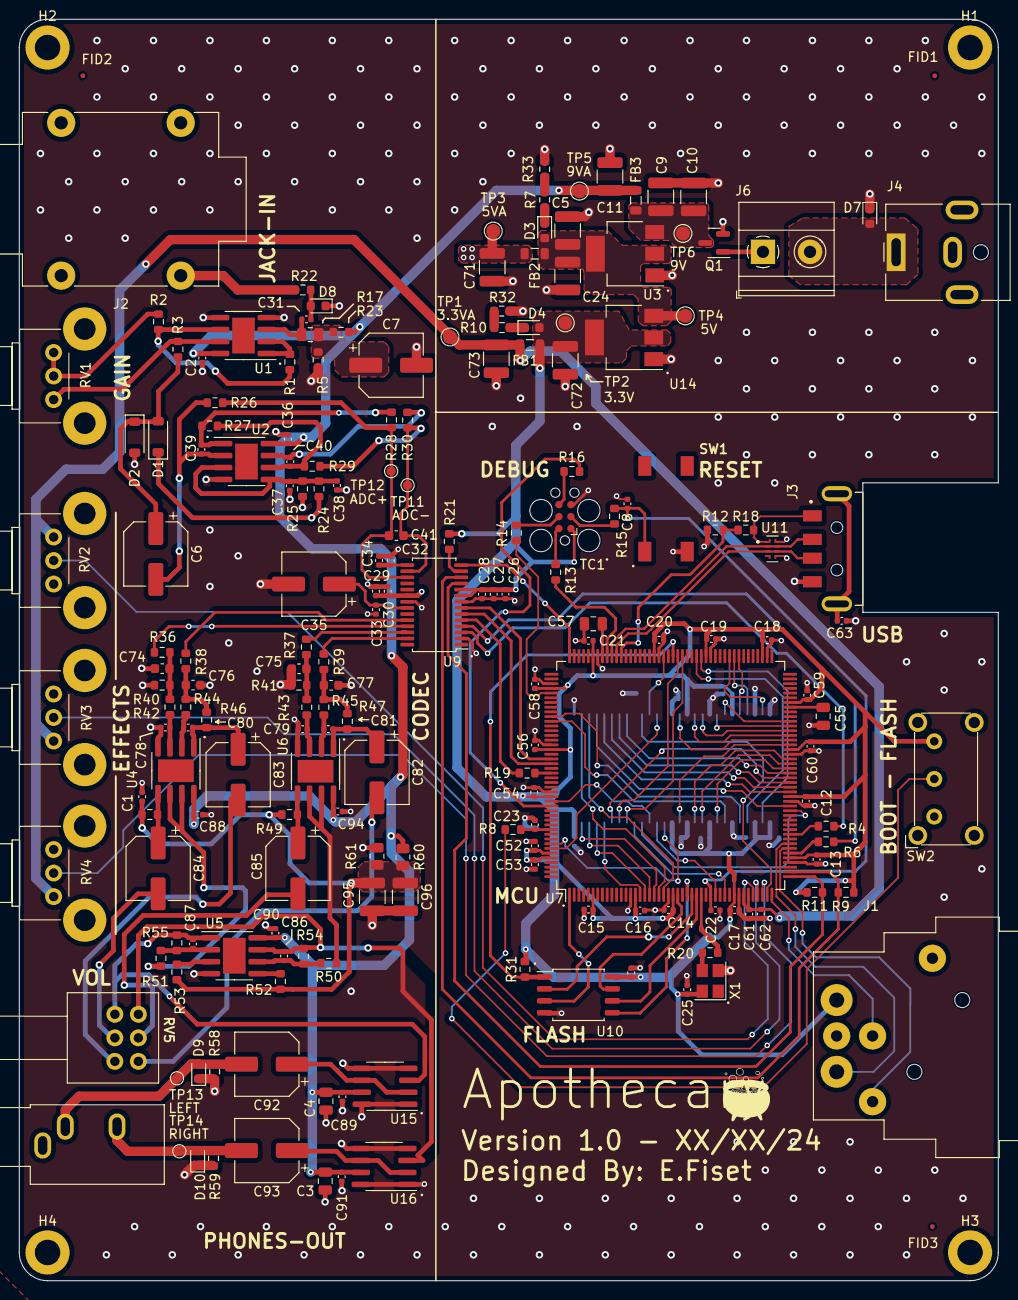
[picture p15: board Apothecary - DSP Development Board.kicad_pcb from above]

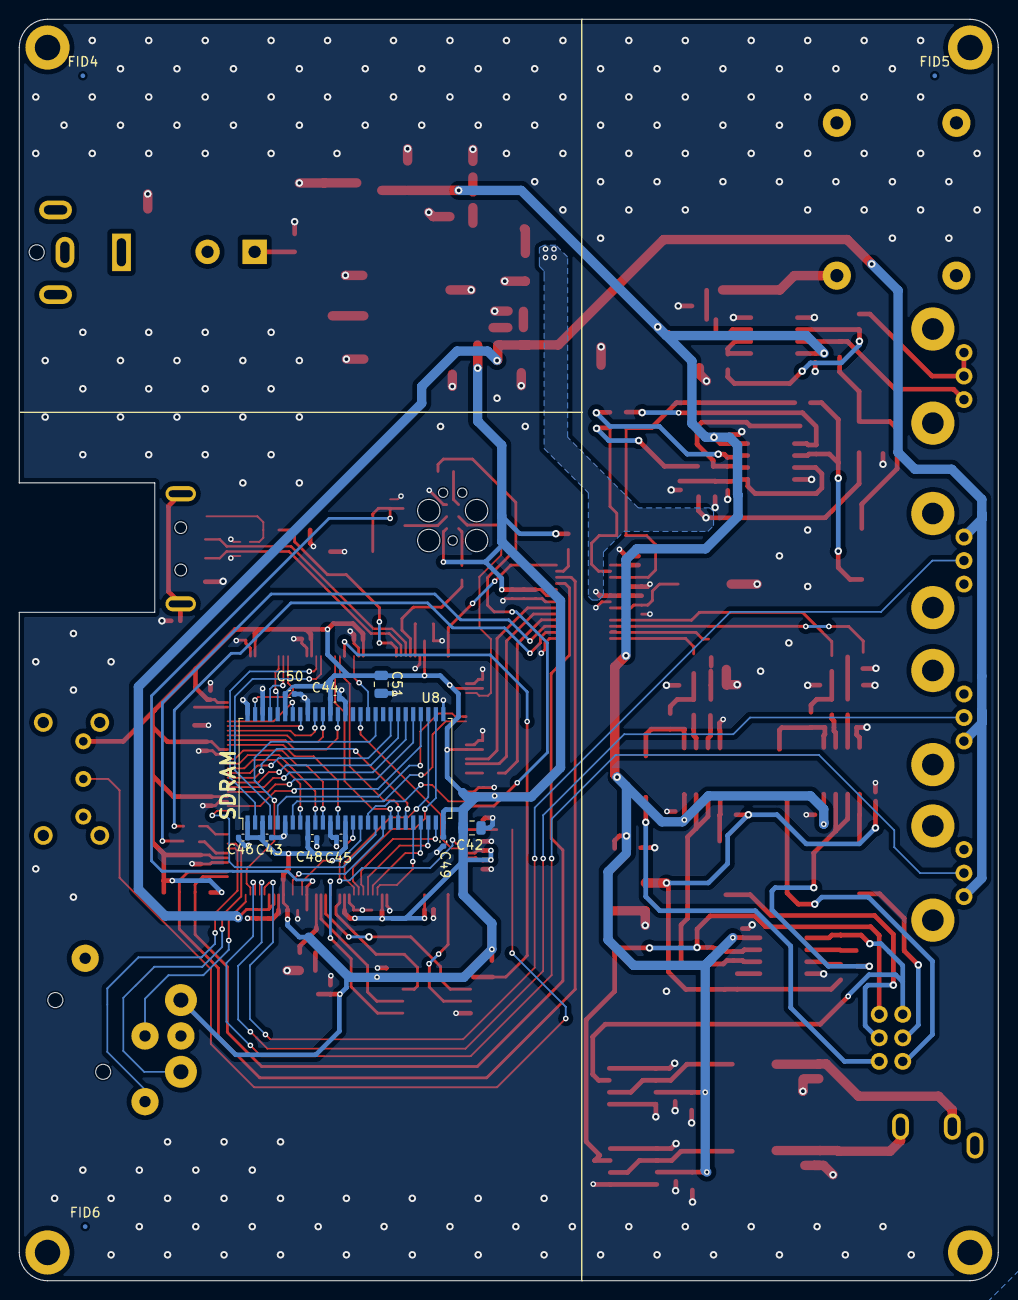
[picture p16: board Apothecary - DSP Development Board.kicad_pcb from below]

Board: 4 copper layers, 104.0 x 134.0 mm, 207 parts (13 on the bottom side), 145 nets.
